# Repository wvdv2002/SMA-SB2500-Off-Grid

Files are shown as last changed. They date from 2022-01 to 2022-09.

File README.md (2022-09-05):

# SMA-SB2500-Off-Grid
The grid tie solar inverter SMA Sunny Boy SB2500 is a beautifully designed transformer isolated grid tie inverter. It is probably possible to convert it to an off grid batter inverter by reprogramming or redesigning the logic  board

Checkout my [hackaday.io](https://hackaday.io/project/183357-grid-tie-inverter-sma-sunny-boy-sb2500-openlogic) page for pictures of the inside of the inverter and a project log.

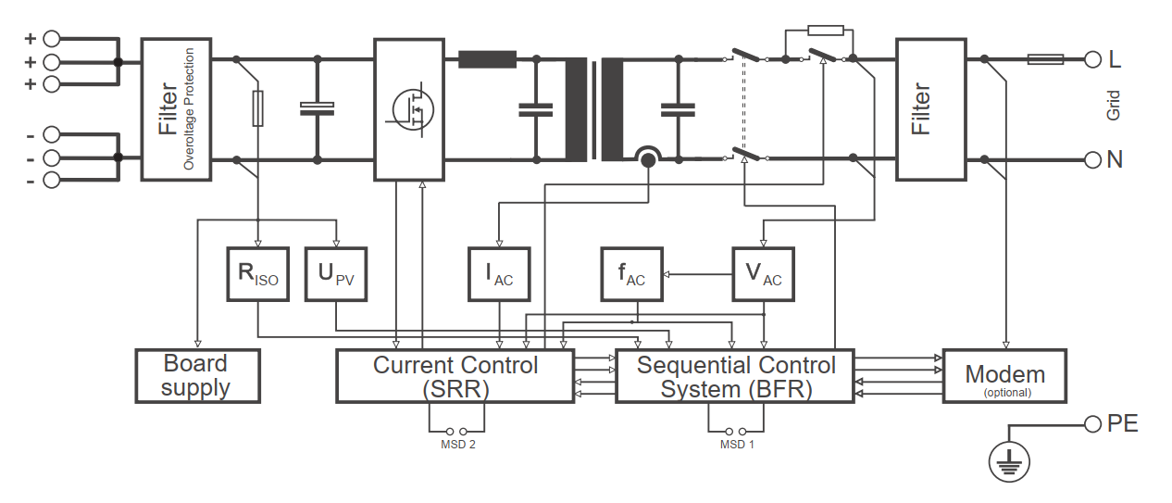
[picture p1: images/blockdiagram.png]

The block diagram from the SB2500 manual.

The inverter has an H-bridge with 4 IGBTs (SKW30NF60) driven by IR2113S mosfet drivers. These drive an 2mH inductor + 4.7uF capacitor step down converter and then a isolation transformer 153V primary/230V secondary 9.6A. On the grid side are three safety relais, EMC filtering and a measurement transformer for the logic board the measure the grid voltages.
All the logic is powered from the DC side, several voltages are generated using a switching power converter which generates all the drive voltages for the IGBT drivers and the logi board.
The logic board contains an SAFC808 microcontroller, probably with an interchangable AT70C020, 2 MBit memory chip, for grid monitoring and sequencing. A DSP56F803 from Freescale provides the switching waveforms. 

The layout is drawn in Kicad. 

Exported kicad images (probably not up to date) are in the images folder. 

The src folder can contain the Freescale DSP code.

The datasheets folder contains datasheets of most of the electronic parts in the inverter.

# Already known
* Switching frequency 16khz
* 250 - 600VDC max input voltage range
* 2200W nominal power
* It is probably challenging to reuse the logic board, as one of the microcontrollers is OTP, maybe it can be bridged and only the DSP used. But then you need a [Freescale USB TAP](https://www.nxp.com/docs/en/user-guide/CWH-UTP-UG.pdf) JTAG programmer to program the DSP. The development environment is not easy to download, but it looks easy to use. 
* The [DEFCON 18 badge](https://media.defcon.org/DEF%20CON%2018/DEF%20CON%2018%20badge/) has used the same development environment and might be a good place to download the development environment and some general guide.

# Already done
* Basic pinout of the logic board connection in Kicad
* Basic layout of the power board important parts in Kicad
* Design new logic board 
* Check if pinout is correct by measuring the voltages on the logic board connector 
* Check all voltage ranges of the voltage measurements on the logic board connector
* Written basic control software
* Light a lightbulb using AC voltage of 100vac at the output of the inverter.

# TODO
* Try to reprogram logic board

# Interesting links
* [Arduino based grid tie inverter repo](https://github.com/MartinStokroos/openMicroInverter)
* [Pic based grid tie inverter repo](https://github.com/rajeshfarswan/UDQ-GRID-1P)
* [STM based grid tie inverter repo](https://github.com/fotherja/Grid_Tie_Inverter)
* [STM based grid tie inverter 2 repo](https://github.com/fotherja/Grid_Tie_Inverter_2)
* [TIVA-C based grid tie inverter](https://github.com/srpoyrek/NIVAS)

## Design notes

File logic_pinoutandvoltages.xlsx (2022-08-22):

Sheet: 25
1 | VSUP1 | 13V |  | Voltages Measured from logic board ground plane
2 | GND | 0V
3 | VSUP2 | -13V
4 | VSUP3 | 3v3
5 | GND | 0V
6 | 5V | 5.09V
7 | GND | 0v
8 | GND | 0v (ground of the 5.09v
9 | AC Modem | 0v
10 | GND | 0v
11 | GND | 0v
12 | GND | 1.409
13 | B1_HIN | 0
14 | B0_LIN | 0
15 | B1_HIN | 0
16 | B1_LIN | 0
17 | GND | 0
18 | 5v | 5.09v
19 | BS_SHUT | 0.034
20 | GND | 0 |  |  | Weird 0 ohm resistor to GND setup, might be indicator if 2500watt or 3000watt or 2000 watt
21 | REL0 | 0
22 | REL0_CHK | 0 | Relay0, 4.08-4.5v if relay is open, otherwise 0, but only if 230v is switched on
23 | REL1_CHK | 0 | Relay1, 4.08-4.5v if relay is open, otherwise 0, but only if 230v is switched on
24 | REL1 | 0
25 | GND | 0
26 | GND | 0
27 | CURSENS | 0 | 15A is 2.5v, -15A is -2.5v. Measurement range is -60A tot 60A, so -10 tot 10v, for 2500watt, you need 2500/230*sqrt(2) = +/- 15A, seems to be buffered by LM258
28 | TRAFO | 0 | @ 230VAC you get -4.88 to 4.88v on this pin. There do not seem to be phase differences
29 | TEMPHEAT | 1.41v | @16 degrees C
30 | VDCBUS | 1.3436 | bij 177.68v, max bus is 650v, so 650/177.68*1.3436 = 4.91v, is 4.91/32*22= |  |  | Buffered by LM258, so just divide down from 5v to 3.3v
31 | VARISTOR | 1.9885 | drops if varistor removed on edge |  |  | Pullup to 5v with 4.7k, 2x pull down to gnd via opamp and diode.
32 | ???, ADC | 1.6198 | ???? |  |  | 100ohm resistor to testpoint, divider with 4.7k to gnd
33 | GND | 0
34 | GND | 0
35 |  | 0 |  | Weird 0 ohm resistor to GND setup, might be indicator if 2500watt or 3000watt or 2000 watt
36 | ?? | 4.5691 |  | Pullup to 5v via 500ohm resistor, to giant square testpoint
37 |  | 0 |  | Weird 0 ohm resistor to GND setup, might be indicator if 2500watt or 3000watt or 2000 watt
38 |  | 0 |  | Weird 0 ohm resistor to GND setup, might be indicator if 2500watt or 3000watt or 2000 watt
39 |  | 0 |  | Weird 0 ohm resistor to GND setup, might be indicator if 2500watt or 3000watt or 2000 watt
40 |  | 0 |  | 1k resistor divider to point, point 10k resistor divider to GND
How to control:
Measure VDCBus, feedforward to PWM signal at 16khz to make 230v (153v before transformer), Use TRAFO input as feedback to correct via PID loop?
Maybe use current measurement and resistance of transformer to feedforward to PWM signal too.

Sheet: LCD pins
n
There are 14 pins to connect to the main board |  |  | 27m21 precision amplifier on LCD board.
 |  |  | 2x7 2.54mm female on LCD board
LCD pin
1 | GND | 14 pin mainboard connector
2 | 5V | 1 | 5V and via 2ohm resistor to 5V LED
3 | Vo | 2 | GND
4 | RS | 3 | EN LCD
5 | R/W | 4 | R/W LCD
6 | EN | 5 | RS LCD
7 | D0 | 6 | LCD Backlight on/off
8 | D1 | 7 | GND
9 | D2 | 8 | microphone amplifier out
10 | D3 | 9 | Switch A, pull to GND
11 | D4 | 10 | Switch B, pull to GND
12 | D5 | 11 | D4
13 | D6 | 12 | D5
14 | D7 | 13 | D6
15 | 5V LED | 14 | D7
16 | GND LED

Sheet: COMM pins
Communication board has 2 connectors
On inverter side:
MAX253 | 1W primary side isolated power supply driver,
HCT14 | Hex inverting schmitt trigger
sfh6156-3 | optocoupler, 4X
comm side:
MAX487E | RS485 chip
KF50 | 5v low drop 0.4v, inhibit is not used and connected to GND
SM712 | 12V TVS diode
 |  |  |  | OPTO
COMM |  | INV |  | 1 | RX RS485/RS232 |  | 6A
1 | COMM PIN 1 | 1 | NC | 2 | TX RS485 |  | 4Y
2 | RS232 RX, OPTO 1 | 2 | NC | 3 | TX ENA |  | 1Y
3 | RS 485 A | 3 | RX opto, 5Y | 4 | RX ENA |  | 2Y
4 | 120ohm to A | 4 | TX ENA, opto 3
5 | RS 485 A | 5 | TX 485, opto 2 |  | 5A - 6Y | connected
6 | RS 485 B | 6 | NC
7 | 50 ohm to GND | 7 | RX ENA, opto 4, high = uit
8 | RS 485 B | 8 | NC
9 | GND | 9 | GND
10 | COMM PIN 1 | 10 | 5v
 |  | 11 | NC
 |  | 12 | 10V
 |  | 13 | receive pin, 3Y
 |  | 14 | NC

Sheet: logicboard
ADR02A | +2.5v voltage reference
hct74 | dual D type flipflop
lp211 | Low power strobed comparator
hct259D | 8 bit Addressable latch
bs62lv256sip5 | 32KByte Sram
at27c020 | 2MBIT OTP EPROM
lm258 | dual opamp
MC33275D−3.3G | 3.3v regulator low drop 300ma
OP177G | ultra precision opamp, 25uV offset
HB02 | 74ahct02 quad NOR Gates
DSP56F803 | 16 bit DSP/microcontroller
safc505 | 8 bit microcontroller
AT25080 | 1Kbyte EEPROM SPI
HCT08 | Quad AND gates
HCT157 | Quad 2 input multiplexer
C07 | 12bit 555 ksps AD742BRT, SPI
C14 | 8 pin package???
HB14 | 74HCT14, hex schmitt trigger inverters
HB32 | Quad 2 input OR gates
HB138 | 74HAHCT138 3 to 8 line decoders
HB574 | Octal D type latches with 3 state outputs and clock
HB573 | Octal D type latches with 3 state outputs and latch enable
HB245 | Octal bus transceivers with 3-state outputs

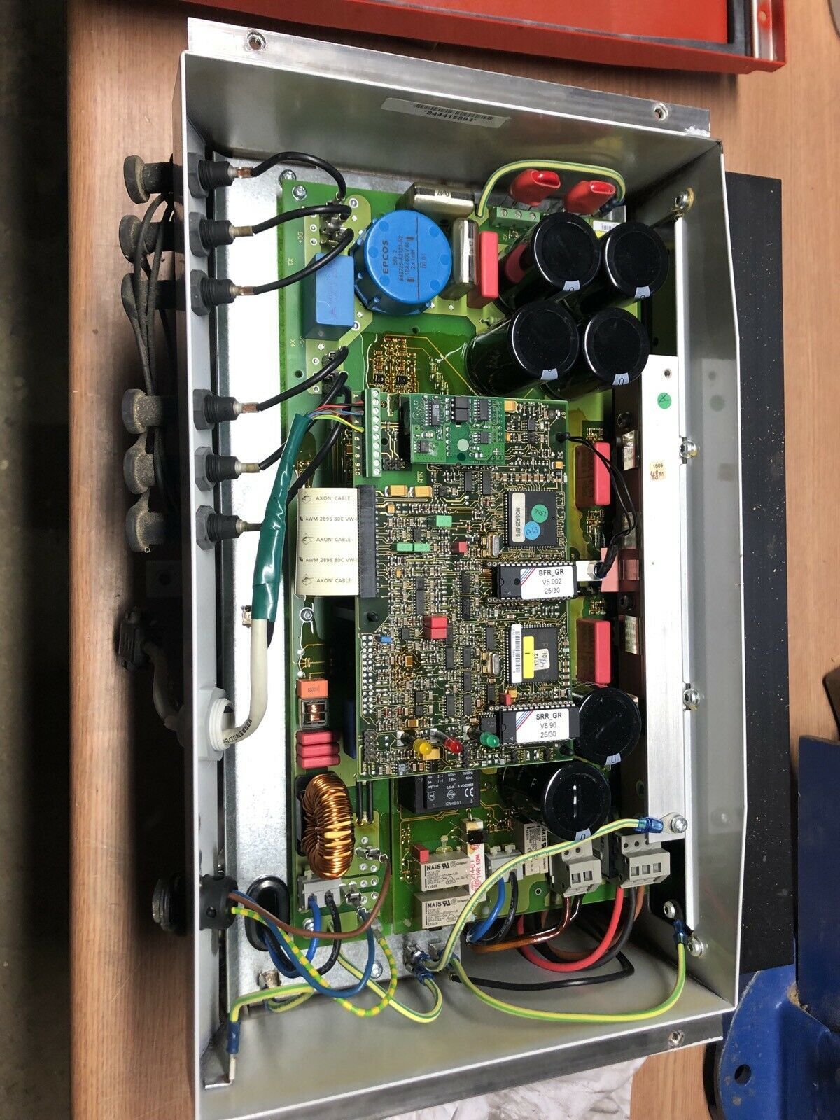
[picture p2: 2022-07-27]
images/olderdesign.jpg

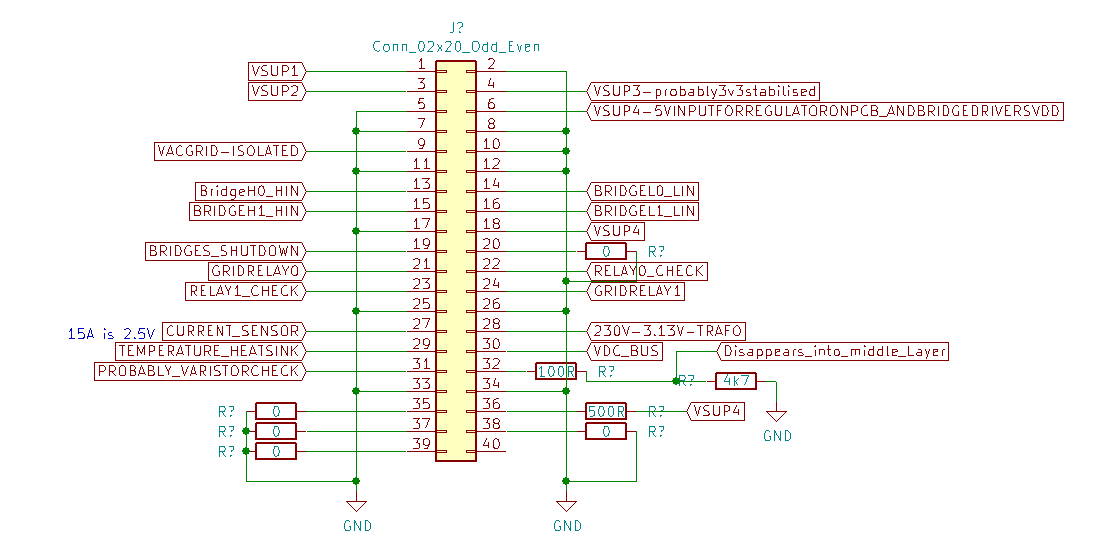
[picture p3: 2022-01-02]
images/logicpinout.png

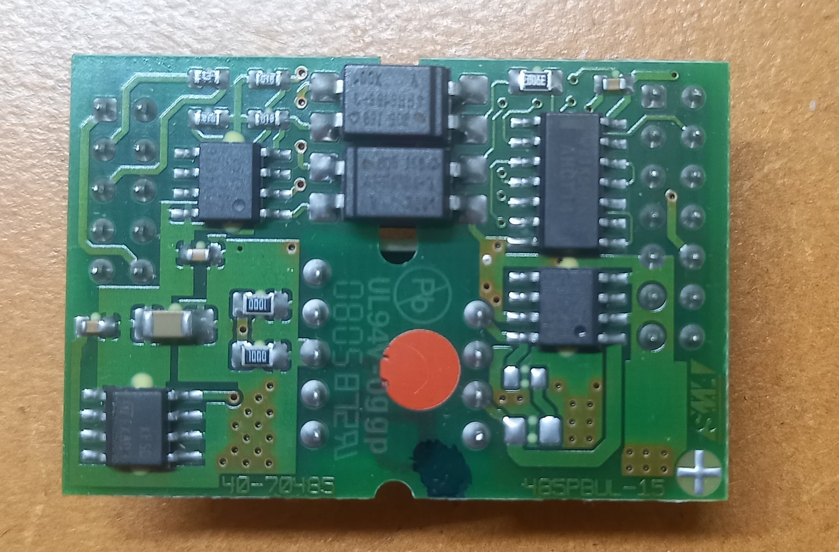
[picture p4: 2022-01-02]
images/commboard.jpg

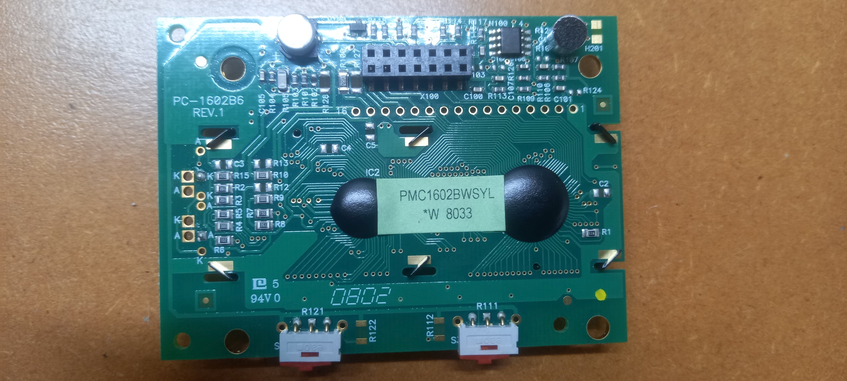
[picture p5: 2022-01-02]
images/lcdunderside.jpg

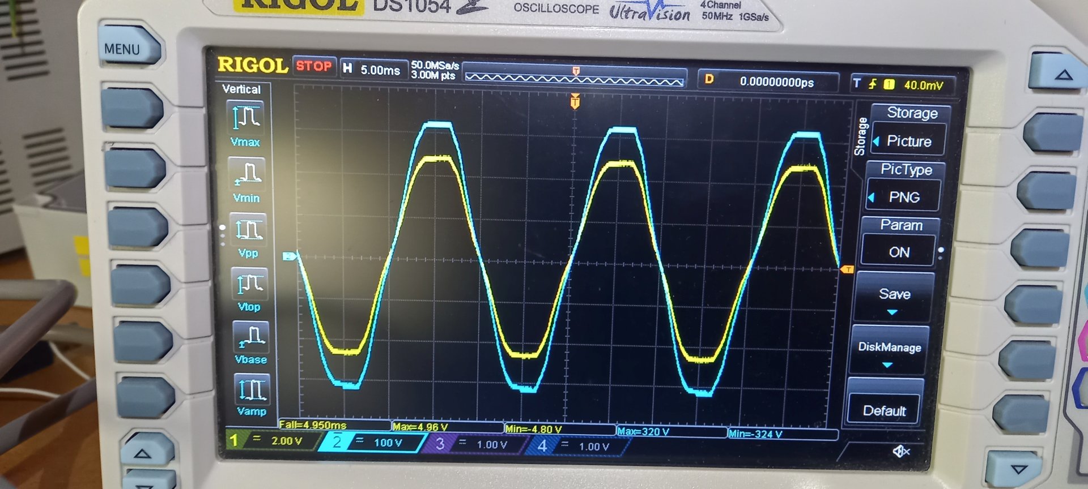
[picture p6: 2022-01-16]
images/waveform230v.jpg

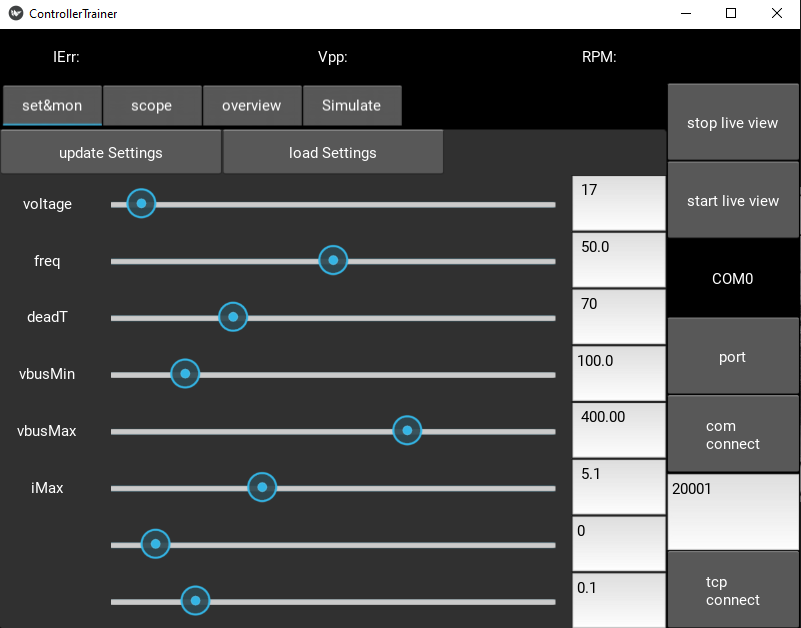
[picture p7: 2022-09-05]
images/newController/ControllerTrainer.png

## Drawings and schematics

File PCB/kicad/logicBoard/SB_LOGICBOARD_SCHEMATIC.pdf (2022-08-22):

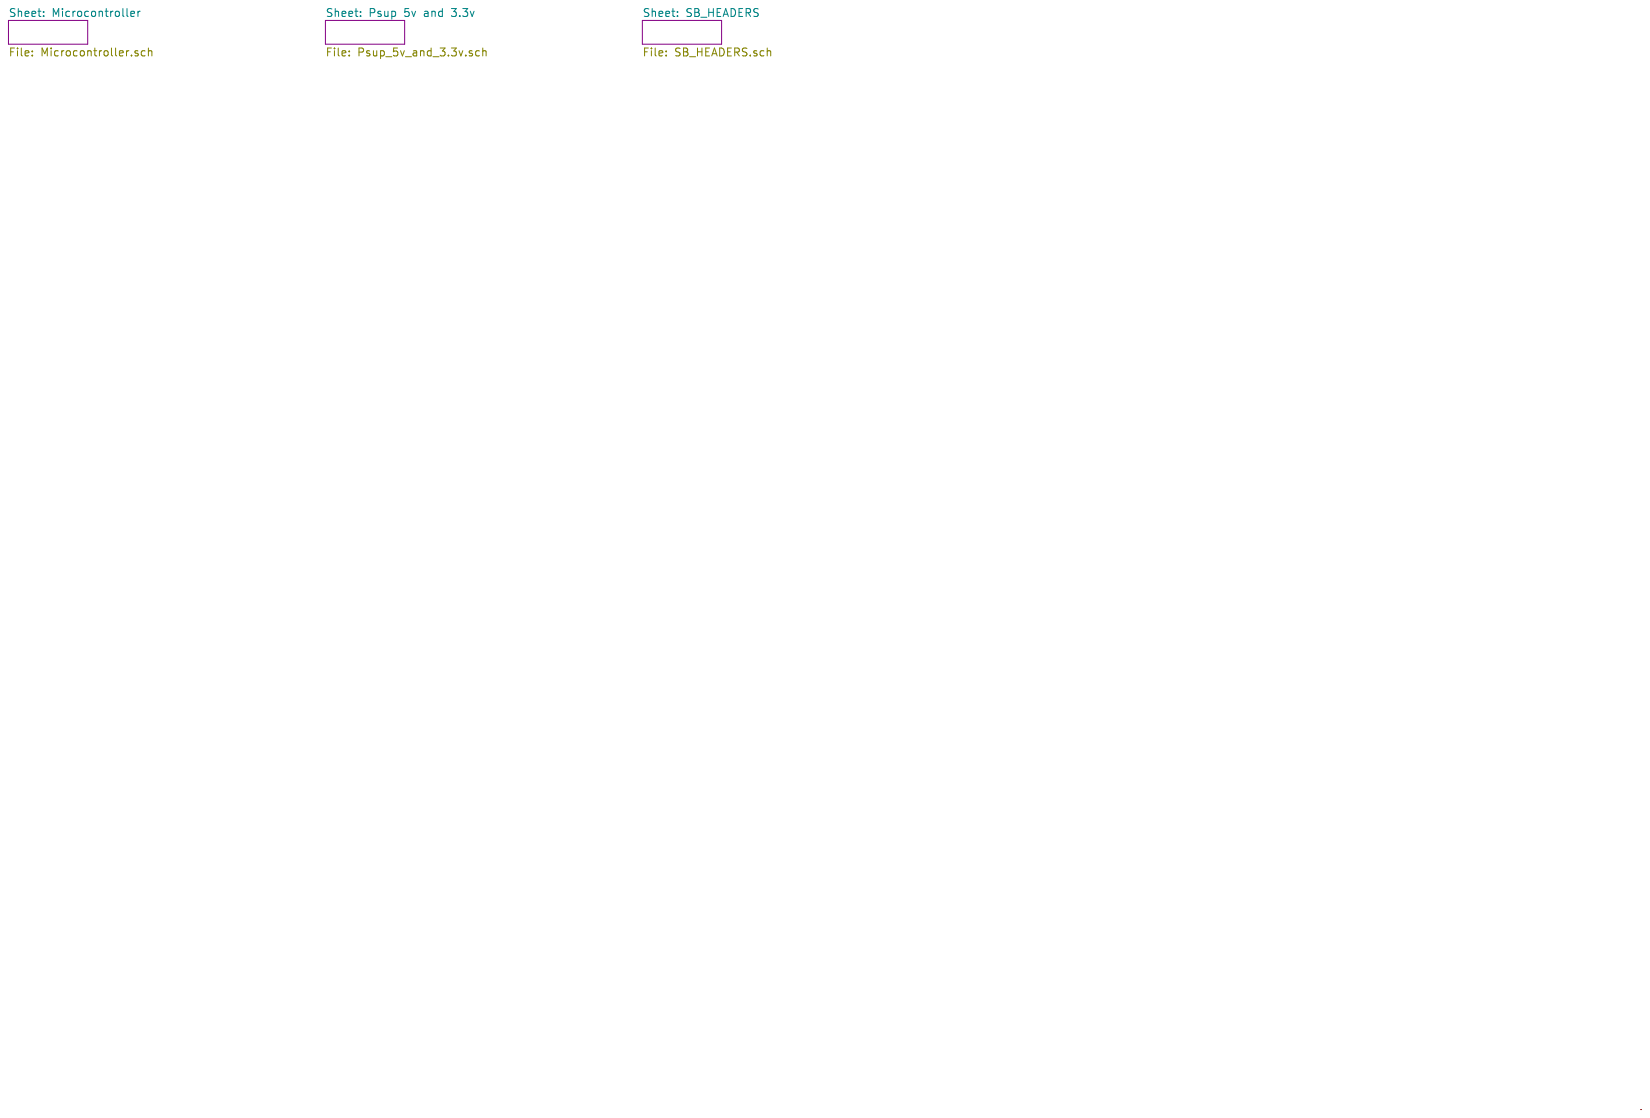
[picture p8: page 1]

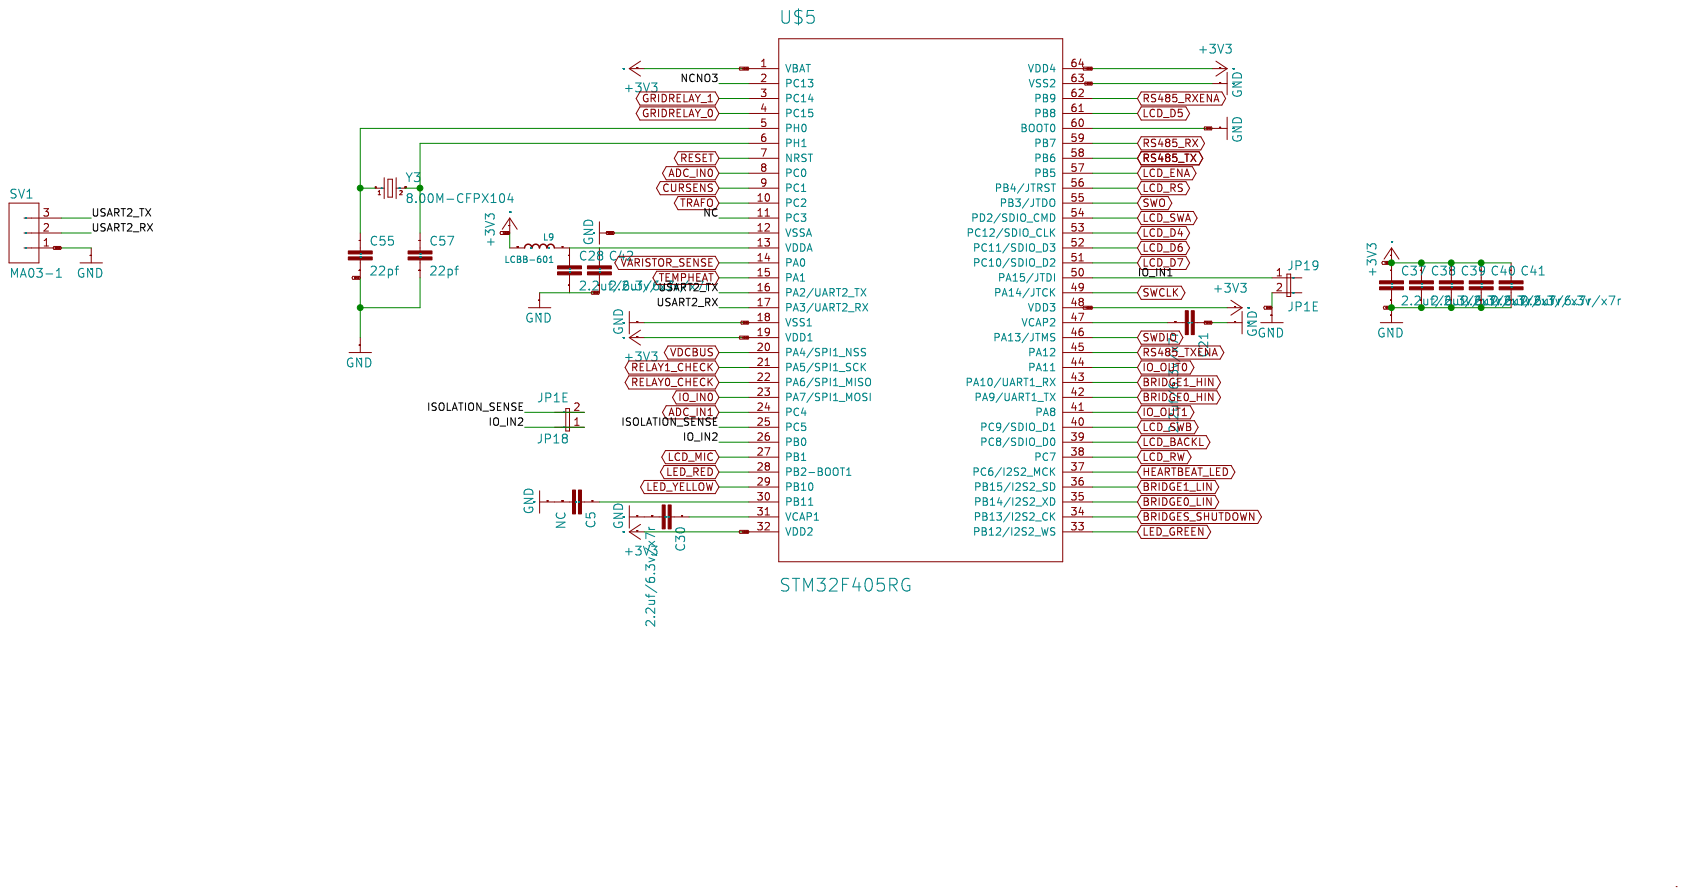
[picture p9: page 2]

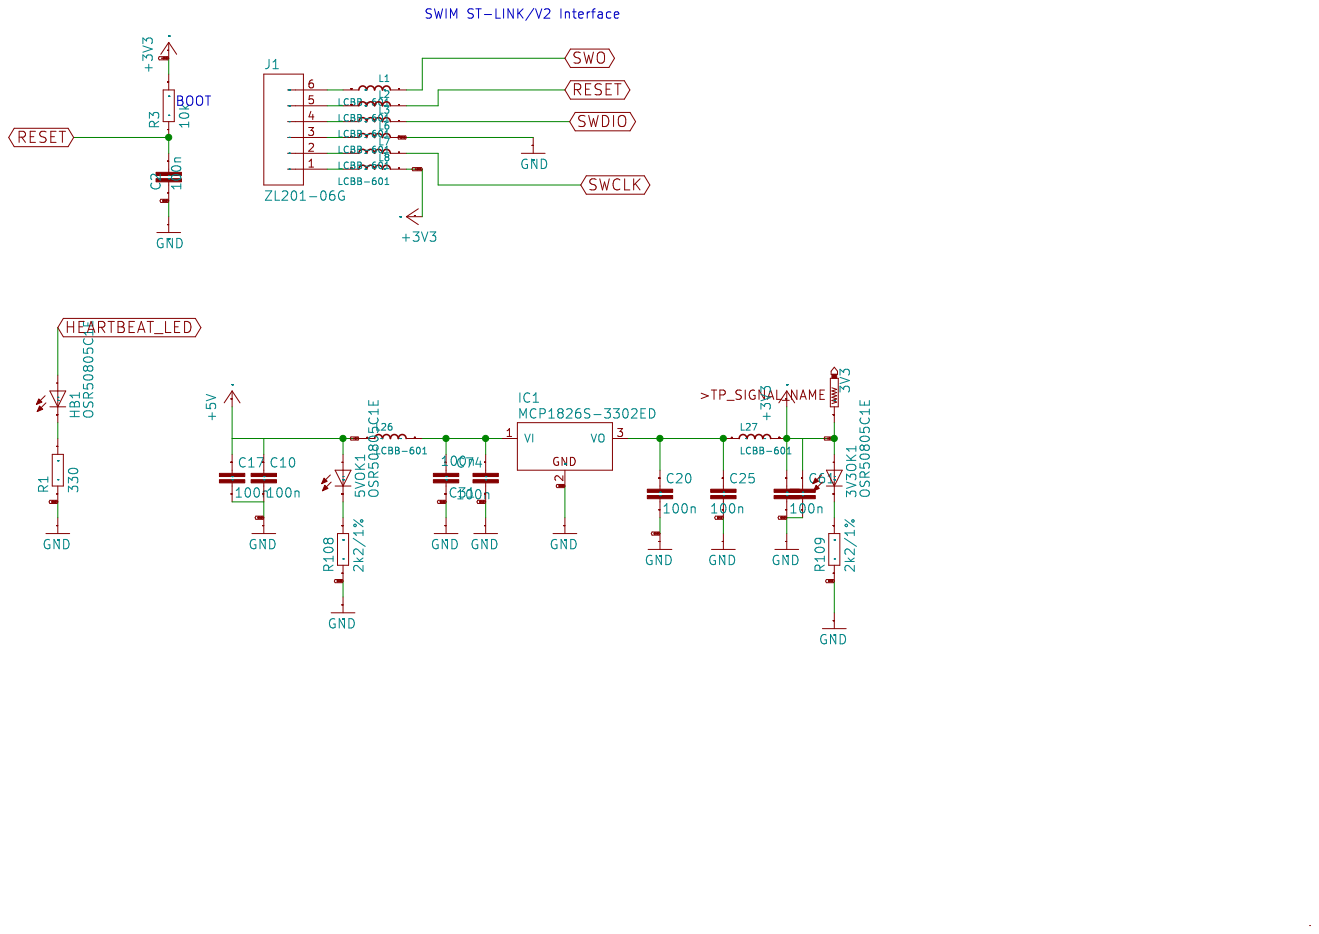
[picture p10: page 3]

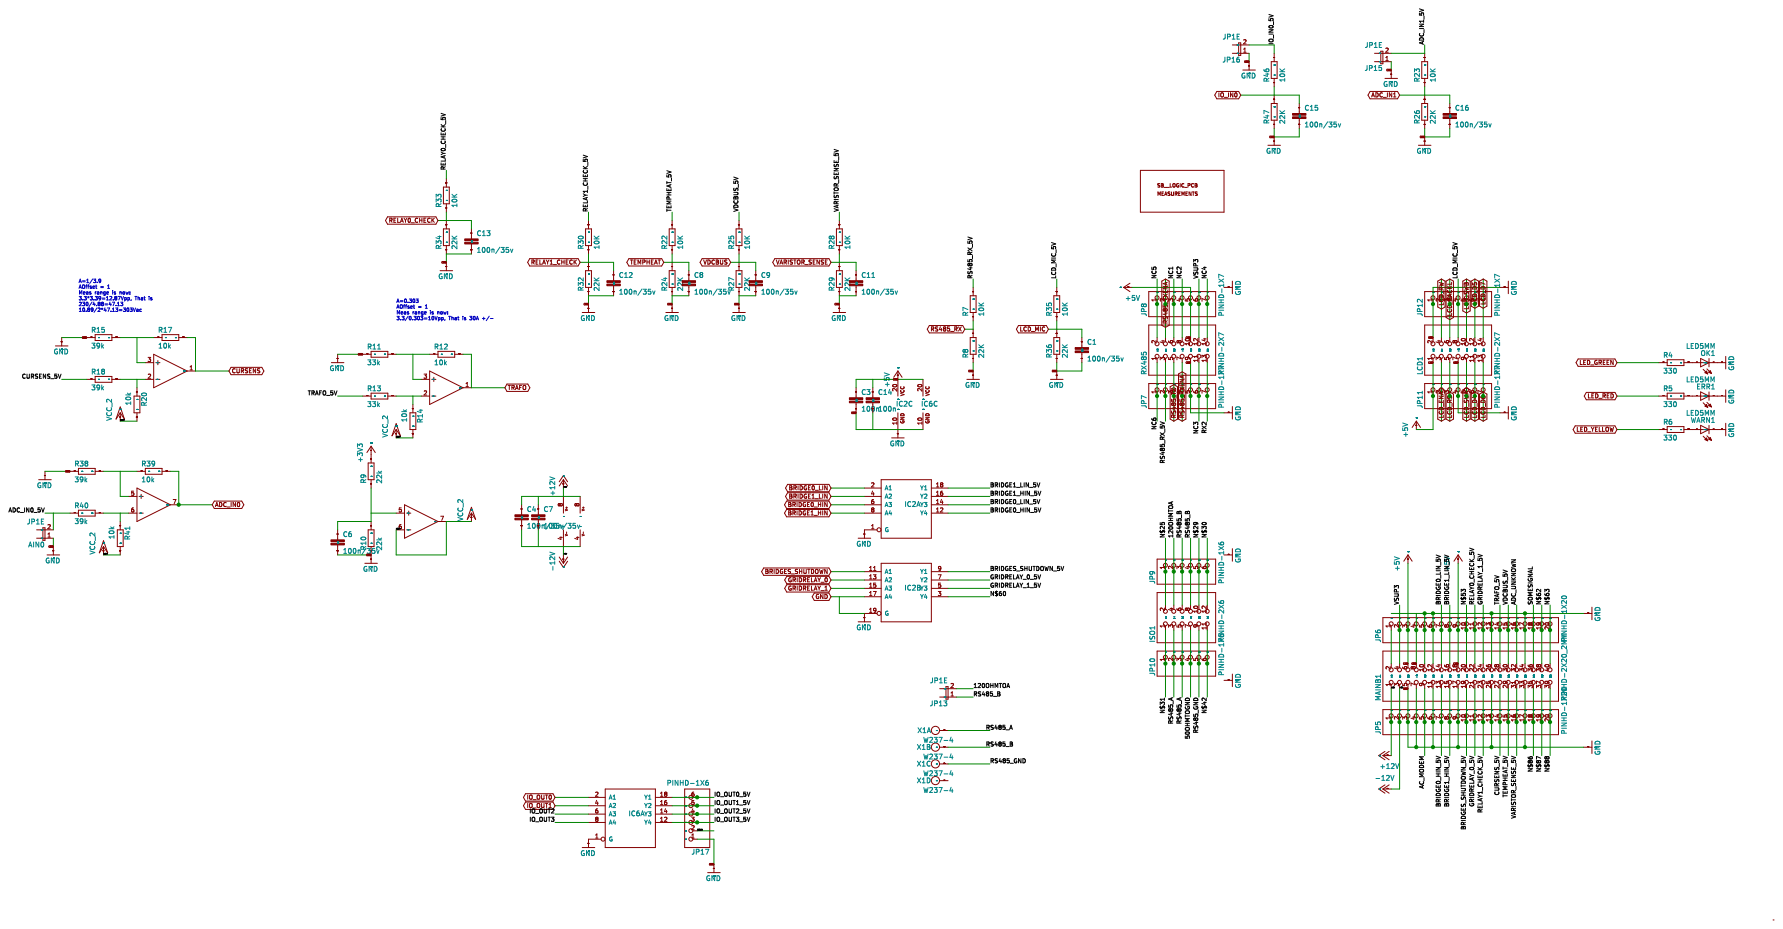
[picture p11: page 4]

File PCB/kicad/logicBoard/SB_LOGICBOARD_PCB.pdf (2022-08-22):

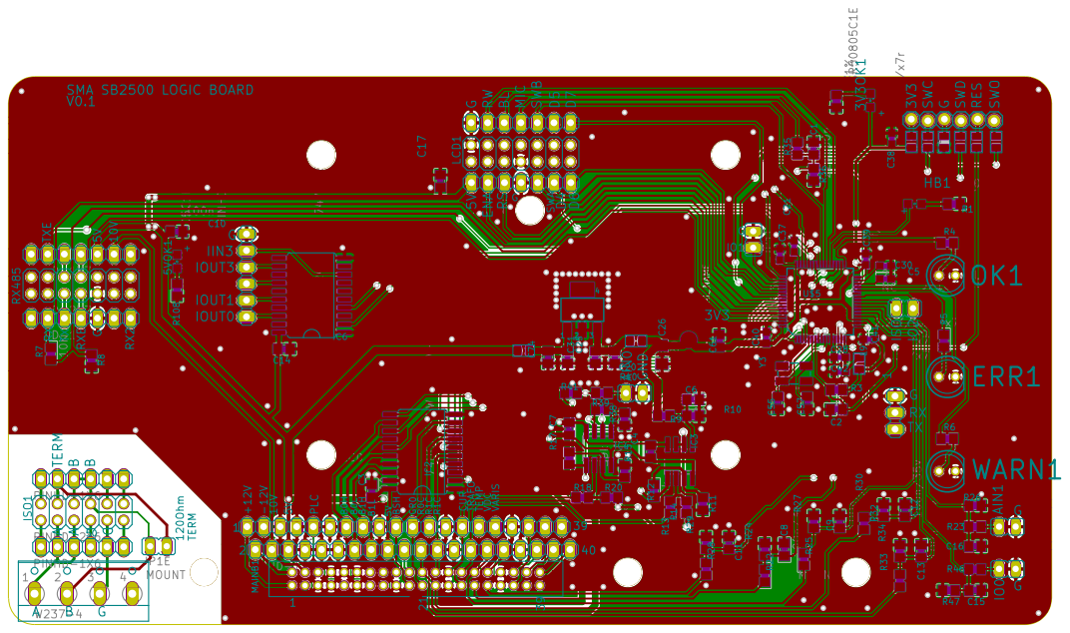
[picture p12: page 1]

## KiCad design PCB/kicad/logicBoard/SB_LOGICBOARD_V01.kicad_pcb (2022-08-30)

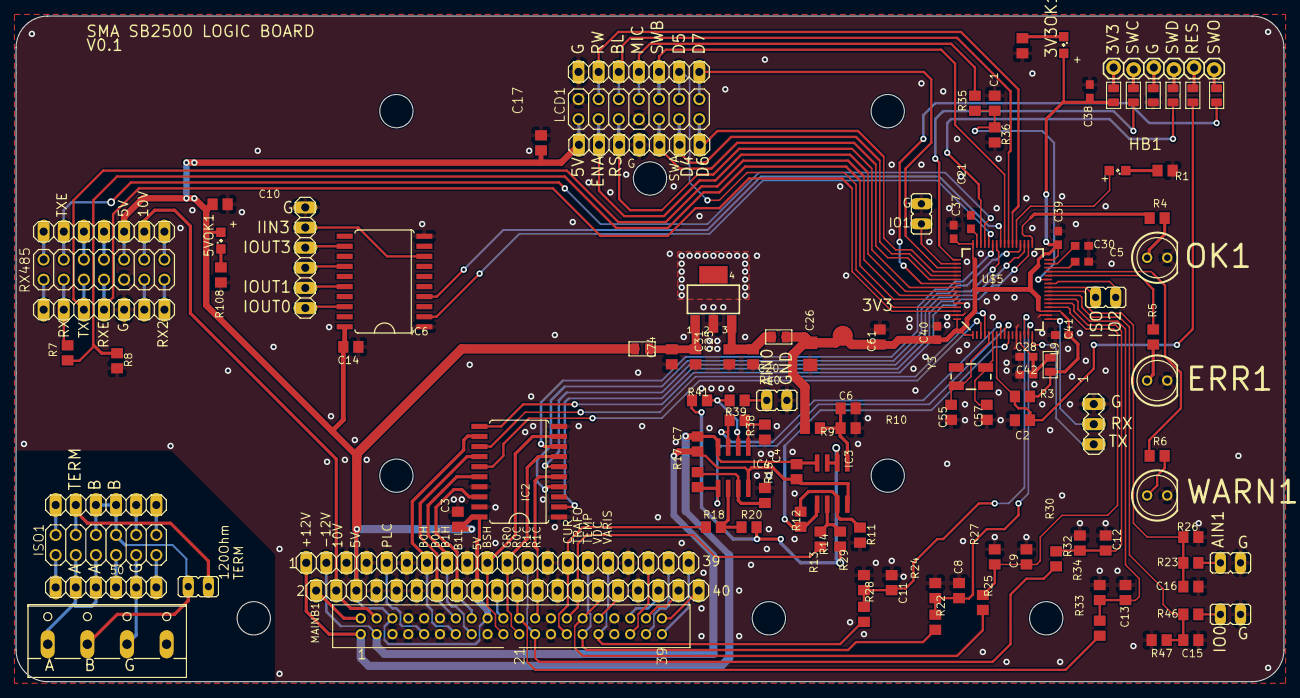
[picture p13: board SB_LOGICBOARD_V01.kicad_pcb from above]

Board: 2 copper layers, 160.0 x 84.0 mm, 119 parts (0 on the bottom side), 132 nets.

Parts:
3V3: NC; B2,54
3V3OK1, 5VOK1: OSR50805C1E; SML0805
AIN0: JP1E; JP1
C1, C4, C6, C7, C8, C9, C11, C12, C13, C15, C16: 100n/35v; C0805
C2, C3, C10, C14, C17, C20, C25, C31, C61, C74: 100n; C0805
C5: NC; C0603
C21, C28, C30, C37, C38, C39, C40, C41, C42: 2.2uf/6.3v/x7r; C0603
C26: 1206DD106KAT2A; C1206
C55, C57: 22pf; C0805
ERR1: LED5MM
HB1: OSR50805C1E; SML0805
IC1: MCP1826S-3302ED; SOT223
IC2, IC6: 74HCT244DW OR 74VHCT541A; SO20W
IC3, IC4: LM358D; SO08
ISO1: PINHD-2X6; 2X06
J1: ZL201-06G; 1X06_LOCK
JP5, JP6: PINHD-1X20; 1X20
JP7, JP8, JP11, JP12: PINHD-1X7; 1X07
JP9, JP10, JP17: PINHD-1X6; 1X06
JP13, JP15, JP16, JP18, JP19: JP1E; JP1
L1, L2, L3, L6, L7, L8, L9, L26, L27: LCBB-601; L0805
LCD1: PINHD-2X7; 2X07
MAINB1: PINHD-2X20_2MM; 2X20_2MM
OK1: LED5MM
R1, R4, R5, R6: 330; R0805
R3, R12, R14, R17, R20, R39, R41: 10k; R0805
R7, R22, R23, R25, R28, R30, R33, R35, R46: 10K; R0805
R8, R24, R26, R27, R29, R32, R34, R36, R47: 22K; R0805
R9, R10: 22k; R0805
R11, R13: 33k; R0805
R15, R18, R38, R40: 39k; R0805
R108, R109: 2k2/1%; R0805
RX485: PINHD-2X7; 2X07
SV1: MA03-1
U$1: SB_LOGIC_PCB; SB-PCB
U$5: STM32F405RG; TQFP64
WARN1: LED5MM
X1: W237-4
Y3: 8.00M-CFPX104; CRYSTAL-SMD-5X3

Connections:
+3V3: 3V3.TP, 3V3OK1.A, C26.2, C37.1, C38.1, C39.1, C40.1, C41.1, C61.2, L8.1, L9.2, L27.2, R3.2, R9.2, U$5.1, U$5.19, U$5.32, U$5.48, U$5.64
+5V: 5VOK1.A, C3.1, C10.2, C14.1, C17.2, IC2.20, IC6.20, JP6.3, JP6.9, JP8.5, JP11.1, L26.1, LCD1.1, MAINB1.6, MAINB1.18, RX485.10
+12V: C4.1, C7.1, IC3.8, IC4.8, JP5.1, MAINB1.1
-12V: C4.2, C7.2, IC3.4, IC4.4, JP5.2, MAINB1.3
/Microcontroller/IO_IN1: JP19.1, U$5.50
/Microcontroller/IO_IN2: JP18.1, U$5.26
/Microcontroller/ISOLATION_SENSE: JP18.2, U$5.25
/Microcontroller/USART2_RX: SV1.2, U$5.17
/Microcontroller/USART2_TX: SV1.3, U$5.16
/SB_HEADERS/50OHMTOGND: ISO1.7, JP10.4
/SB_HEADERS/120OHMTOA: ISO1.4, JP9.2, JP13.2
/SB_HEADERS/AC_MODEM: JP5.5, MAINB1.9
/SB_HEADERS/ADC_IN0_5V: AIN0.2, R40.1
/SB_HEADERS/ADC_IN1_5V: JP15.2, R23.2
/SB_HEADERS/ADC_UNKNOWN: JP6.16, MAINB1.32
/SB_HEADERS/BRIDGE0_HIN_5V: IC2.12, JP5.7, MAINB1.13
/SB_HEADERS/BRIDGE0_LIN_5V: IC2.14, JP6.7, MAINB1.14
/SB_HEADERS/BRIDGE1_HIN_5V: IC2.16, JP5.8, MAINB1.15
/SB_HEADERS/BRIDGE1_LIN_5V: IC2.18, JP6.8, MAINB1.16
/SB_HEADERS/BRIDGES_SHUTDOWN_5V: IC2.9, JP5.10, MAINB1.19
/SB_HEADERS/CURSENS_5V: JP5.14, MAINB1.27, R18.1
/SB_HEADERS/GRIDRELAY_0_5V: IC2.7, JP5.11, MAINB1.21
/SB_HEADERS/GRIDRELAY_1_5V: IC2.5, JP6.12, MAINB1.24
/SB_HEADERS/IO_IN0_5V: JP16.2, R46.2
/SB_HEADERS/IO_OUT0_5V: IC6.18, JP17.6
/SB_HEADERS/IO_OUT1_5V: IC6.16, JP17.5
/SB_HEADERS/IO_OUT2_5V: IC6.14, JP17.4
/SB_HEADERS/IO_OUT3: IC6.8, JP17.2
/SB_HEADERS/IO_OUT3_5V: IC6.12, JP17.3
/SB_HEADERS/LCD_MIC_5V: JP12.4, LCD1.8, R35.2
/SB_HEADERS/N$25: ISO1.2, JP9.1
/SB_HEADERS/N$29: ISO1.10, JP9.5
/SB_HEADERS/N$30: ISO1.12, JP9.6
/SB_HEADERS/N$31: ISO1.1, JP10.1
/SB_HEADERS/N$42: ISO1.11, JP10.6
/SB_HEADERS/N$53: JP6.10, MAINB1.20
/SB_HEADERS/N$62: JP6.19, MAINB1.38
/SB_HEADERS/N$63: JP6.20, MAINB1.40
/SB_HEADERS/N$86: JP5.18, MAINB1.35
/SB_HEADERS/N$87: JP5.19, MAINB1.37
/SB_HEADERS/N$88: JP5.20, MAINB1.39
/SB_HEADERS/NC1: JP8.3, RX485.6
/SB_HEADERS/NC2: JP8.4, RX485.8
/SB_HEADERS/NC3: JP7.6, RX485.11
/SB_HEADERS/NC4: JP8.7, RX485.14
/SB_HEADERS/NC5: JP8.1, RX485.2
/SB_HEADERS/NC6: JP7.1, RX485.1
/SB_HEADERS/RELAY0_CHECK_5V: JP6.11, MAINB1.22, R33.2
/SB_HEADERS/RELAY1_CHECK_5V: JP5.12, MAINB1.23, R30.2
/SB_HEADERS/RS485_A: ISO1.3, ISO1.5, JP10.2, JP10.3, X1.1
/SB_HEADERS/RS485_B: ISO1.6, ISO1.8, JP9.3, JP9.4, JP13.1, X1.2
/SB_HEADERS/RS485_GND: ISO1.9, JP10.5, X1.3
/SB_HEADERS/RS485_RX_5V: JP7.2, R7.2, RX485.3
/SB_HEADERS/RX2: JP7.7, RX485.13
/SB_HEADERS/SOMESIGNAL: JP6.18, MAINB1.36
/SB_HEADERS/TEMPHEAT_5V: JP5.15, MAINB1.29, R22.2
/SB_HEADERS/TRAFO_5V: JP6.14, MAINB1.28, R13.1
/SB_HEADERS/VARISTOR_SENSE_5V: JP5.16, MAINB1.31, R28.2
/SB_HEADERS/VDCBUS_5V: JP6.15, MAINB1.30, R25.2
/SB_HEADERS/VSUP3: JP6.2, JP8.6, MAINB1.4, RX485.12
ADC_IN0: IC4.7, R39.2, U$5.8
ADC_IN1: C16.1, R23.1, R26.2, U$5.24
BRIDGE0_HIN: IC2.6, U$5.42
BRIDGE0_LIN: IC2.2, U$5.35
BRIDGE1_HIN: IC2.8, U$5.43
BRIDGE1_LIN: IC2.4, U$5.36
BRIDGES_SHUTDOWN: IC2.11, U$5.34
CURSENS: IC4.1, R17.2, U$5.9
GND: AIN0.1, C1.2, C2.1, C3.2, C5.2, C6.2, C8.2, C9.2, C10.1, C11.2, C12.2, C13.2, C14.2, C15.2, C16.2, C17.1, C20.1, C21.1, C25.1, C26.1, C28.2, C30.2, C31.1, C37.2, C38.2, C39.2, C40.2, C41.2, C42.2, C55.2, C57.2, C61.1, C74.2, ERR1.K, IC1.2, IC2.1, IC2.10, IC2.17, IC2.19, IC6.1, IC6.10, JP5.3, JP5.4, JP5.6, JP5.9, JP5.13, JP5.17, JP6.4, JP6.5, JP6.6, JP6.13, JP6.17, JP7.5, JP11.4, JP12.1, JP15.1, JP16.1, JP17.1, JP19.2, L6.1, LCD1.2, LCD1.7, MAINB1.5, MAINB1.7, MAINB1.8, MAINB1.10, MAINB1.11, MAINB1.12, MAINB1.17, MAINB1.25, MAINB1.26, MAINB1.33, MAINB1.34, OK1.K, R1.1, R8.1, R10.1, R11.1, R15.1, R24.1, R26.1, R27.1, R29.1, R32.1, R34.1, R36.1, R38.1, R47.1, R108.1, R109.1, RX485.9, SV1.1, U$5.12, U$5.18, U$5.60, U$5.63, WARN1.K
GRIDRELAY_0: IC2.13, U$5.4
GRIDRELAY_1: IC2.15, U$5.3
HEARTBEAT_LED: HB1.A, U$5.37
IO_IN0: C15.1, R46.1, R47.2, U$5.23
IO_OUT0: IC6.2, U$5.44
IO_OUT1: IC6.4, U$5.41
LCD_BACKL: JP12.3, LCD1.6, U$5.39
LCD_D4: JP11.6, LCD1.11, U$5.53
LCD_D5: JP12.6, LCD1.12, U$5.61
LCD_D6: JP11.7, LCD1.13, U$5.52
LCD_D7: JP12.7, LCD1.14, U$5.51
LCD_ENA: JP11.2, LCD1.3, U$5.57
LCD_MIC: C1.1, R35.1, R36.2, U$5.27
LCD_RS: JP11.3, LCD1.5, U$5.56
LCD_RW: JP12.2, LCD1.4, U$5.38
LCD_SWA: JP11.5, LCD1.9, U$5.54
LCD_SWB: JP12.5, LCD1.10, U$5.40
LED_GREEN: R4.1, U$5.33
LED_RED: R5.1, U$5.28
LED_YELLOW: R6.1, U$5.29
unnamed: 3V3OK1.C, R109.2
unnamed: 5VOK1.C, R108.2
unnamed: C5.1, U$5.30
unnamed: C6.1, IC3.5, R9.1, R10.2
unnamed: C20.2, C25.2, IC1.3, L27.1
unnamed: C21.2, U$5.47
unnamed: C28.1, C42.1, L9.1, U$5.13
unnamed: C30.1, U$5.31
unnamed: C31.2, C74.1, IC1.1, L26.2
unnamed: C55.1, U$5.5, Y3.1
unnamed: C57.1, U$5.6, Y3.3
unnamed: ERR1.A, R5.2
unnamed: HB1.C, R1.2
unnamed: IC3.2, R13.2, R14.1
unnamed: IC3.3, R11.2, R12.1
unnamed: IC4.2, R18.2, R20.1
unnamed: IC4.3, R15.2, R17.1
unnamed: IC4.5, R38.2, R39.1
unnamed: IC4.6, R40.2, R41.1
unnamed: J1.1, L8.2
unnamed: J1.2, L7.2
unnamed: J1.3, L6.2
unnamed: J1.4, L3.2
unnamed: J1.5, L2.2
unnamed: J1.6, L1.2
unnamed: JP6.1, MAINB1.2
unnamed: OK1.A, R4.2
unnamed: R6.2, WARN1.A
RELAY0_CHECK: C13.1, R33.1, R34.2, U$5.22
RELAY1_CHECK: C12.1, R30.1, R32.2, U$5.21
RESET: C2.2, L2.1, R3.1, U$5.7
RS485_RX: R7.1, R8.2, U$5.59
RS485_RXENA: JP7.4, RX485.7, U$5.62
RS485_TX: JP7.3, RX485.5, U$5.58
RS485_TXENA: JP8.2, RX485.4, U$5.45
SWCLK: L7.1, U$5.49
SWDIO: L3.1, U$5.46
SWO: L1.1, U$5.55
TEMPHEAT: C8.1, R22.1, R24.2, U$5.15
TRAFO: IC3.1, R12.2, U$5.10
VARISTOR_SENSE: C11.1, R28.1, R29.2, U$5.14
VCC/2: IC3.6, IC3.7, R14.2, R20.2, R41.2
VDCBUS: C9.1, R25.1, R27.2, U$5.20

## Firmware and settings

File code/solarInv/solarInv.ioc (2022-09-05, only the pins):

Mcu.UserName=STM32F405RGTx
PA0-WKUP.Signal=ADCx_IN0
PA1.GPIO_Label=TEMPHEAT
PA1.Signal=ADCx_IN1
PA10.GPIO_Label=BRIDGE1_HIN
PA10.Signal=S_TIM1_CH3
PA11.GPIO_Label=IO_OUT0
PA11.Signal=GPIO_Output
PA12.GPIO_Label=RS485_TXENA
PA12.Signal=GPIO_Output
PA13.Signal=SYS_JTMS-SWDIO
PA14.Signal=SYS_JTCK-SWCLK
PA15.GPIO_Label=IO_IN1
PA15.Signal=GPIO_Input
PA2.GPIO_Label=USART2_TX
PA2.Signal=USART2_TX
PA3.GPIO_Label=USART2_RX
PA3.Signal=USART2_RX
PA4.GPIO_Label=VDCBUS
PA4.Signal=ADCx_IN4
PA5.GPIO_Label=RELAY_CHECK1
PA5.Signal=ADCx_IN5
PA6.GPIO_Label=RELAY_CHECK0
PA6.Signal=ADCx_IN6
PA7.GPIO_Label=IO_IN0
PA7.Signal=ADCx_IN7
PA8.GPIO_Label=IO_OUT1
PA8.Signal=GPIO_Output
PA9.GPIO_Label=BRIDGE0_HIN
PA9.Signal=S_TIM1_CH2
PB0.GPIO_Label=IO_IN2
PB0.Signal=ADCx_IN8
PB1.GPIO_Label=LCD_MIC
PB1.Signal=ADCx_IN9
PB10.GPIO_Label=LED_YELLOW
PB10.Signal=GPIO_Output
PB11.GPIO_Label=DONOTUSECOMPATIBILITY
PB11.Signal=GPIO_Input
PB12.GPIO_Label=LED_GREEN
PB12.Signal=GPIO_Output
PB13.GPIO_Label=BRIDGES_SHUTDOWN
PB13.Signal=GPIO_Output
PB14.GPIO_Label=BRIDGE0_LIN
PB14.Signal=TIM1_CH2N
PB15.GPIO_Label=BRIDGE1_LIN
PB15.Signal=TIM1_CH3N
PB2.GPIO_Label=LED_RED
PB2.Signal=GPIO_Output
PB3.Signal=SYS_JTDO-SWO
PB4.GPIO_Label=LCD_RS
PB4.Signal=GPIO_Output
PB5.GPIO_Label=LCD_ENA
PB5.Signal=GPIO_Output
PB6.GPIO_Label=RS485_TX
PB6.Signal=USART1_TX
PB7.GPIO_Label=RS485_RX
PB7.Signal=USART1_RX
PB8.GPIO_Label=LCD_D5
PB8.Signal=GPIO_Output
PB9.GPIO_Label=RS485_RXENA
PB9.Signal=GPIO_Output
PC0.GPIO_Label=ADC_IN0
PC0.Signal=ADCx_IN10
PC1.GPIO_Label=CURSENS
PC1.Signal=ADCx_IN11
PC10.GPIO_Label=LCD_D7
PC10.Signal=GPIO_Output
PC11.GPIO_Label=LCD_D6
PC11.Signal=GPIO_Output
PC12.GPIO_Label=LCD_D4
PC12.Signal=GPIO_Output
PC14-OSC32_IN.GPIO_Label=GRIDRELAY_1
PC14-OSC32_IN.Signal=GPIO_Output
PC15-OSC32_OUT.GPIO_Label=GRIDRELAY_0
PC15-OSC32_OUT.Signal=GPIO_Output
PC2.GPIO_Label=TRAFO
PC2.Signal=ADCx_IN12
PC4.GPIO_Label=ADC_IN1
PC4.Signal=ADCx_IN14
PC5.GPIO_Label=ISOLATION_SENSE
PC5.Signal=ADCx_IN15
PC6.GPIO_Label=LED_HEARTBEAT
PC6.Signal=GPIO_Output
PC7.GPIO_Label=LCD_RW
PC7.Signal=GPIO_Output
PC8.GPIO_Label=LCD_BACKL
PC8.Signal=GPIO_Output
PC9.GPIO_Label=LCD_SWB
PC9.Signal=GPIO_Input
PD2.GPIO_Label=LCD_SWA
PD2.Signal=GPIO_Input

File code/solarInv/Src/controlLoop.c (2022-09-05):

/*
 * controlLoop.c
 *
 *  Created on: 11 aug. 2017
 *      Author: wvdv2
 */
#include "HardwareDefines.h"
#include "controlLoop.h"
#include "controlMonitor.h"
#include "filterCoeff.h"
#include "tm_stm32_filters.h"
#include "PID.h"
#include "temperature/Thermistor.h"
#include "libRelay.h"
#include "fanTask.h"
//#include "syncLoop.h"
#include "stm32f4xx_hal.h"
#include "arm_math.h"
adc3Results_t adc3Results[FILTERDEPTH];
adc2Results_t adc2Results[FILTERDEPTH];
adc1Results_t adc1Results[FILTERDEPTH];

solarFullControlState_t systemState;
solarSetPoints_t setPoint;
solarSetPoints_t setPointCopy;
solarAuxInputs_t auxInputs;
PID_t capacitorPid;

bool updateControl = false;
bool updateSetPoint = false;
uint32_t closeRelayTime=0;
float voutNow= 0.0;

void calculateTemperature(void);

#define DCRATIO (float) 0.999
TM_FILTER_FIR_F32_t* currentFIR;
TM_FILTER_FIR_F32_t* uCapFIR;
extern TIM_HandleTypeDef htim4;
extern TIM_HandleTypeDef htim2;

#define min(a, b) (((a) < (b)) ? (a) : (b))
#define max(a, b) (((a) > (b)) ? (a) : (b))

void controlLoop(void){
//	HAL_GPIO_WritePin(TEST_PIN_GPIO_Port, TEST_PIN_Pin, GPIO_PIN_SET);

	if(updateSetPoint){
		memcpy(&setPoint,&setPointCopy,sizeof(solarSetPoints_t));
//		pidSetTunings(&capacitorPid,setPoint.UCapP,setPoint.UCapI,setPoint.UCapD,P_ON_E);
//		auxInputs.Vpp = syncCalculateVpp();
		updateSetPoint = false;
		htim1.Instance->BDTR = (htim1.Instance->BDTR & 0xFFFFFF00) | setPoint.deadTime;
	}
	calculateInputs();
	calculateFilters();
	calculateState();

	switch(systemState.controlState.controlTaskState){
	case CONTROL_IDLE:
		if(HAL_GetTick()>10000){
			systemState.controlState.controlTaskState = CONTROL_WAITFOR_SAFESTART;
		}
		setDutyCycle(0.0);
		break;
	case CONTROL_WAITFOR_SAFESTART:
		HAL_GPIO_WritePin(BRIDGES_SHUTDOWN_GPIO_Port, BRIDGES_SHUTDOWN_Pin, 0);
		voutNow = 0.0;
		systemState.controlState.controlTaskState = CONTROL_RUNNING;
		__HAL_TIM_SetCounter(&htim2,0);
		HAL_TIM_Base_Start(&htim2);
		break;

	case CONTROL_RUNNING:
		setDutyCycle(getDutyCycle());
		break;

	case CONTROL_FIXED_DUTY_CYLE:
//		setDutyCycle(getDutyCycle());
		break;

	case CONTROL_STOPANDRESET:
		setDutyCycle(0.0);
		break;

	case CONTROL_SAFETY:
	case CONTROL_OVERVOLTAGE:
	case CONTROL_STOPPING:
	case CONTROL_OVERTEMPERATURE:
//		if(systemState.controlState.UCap<(float)7.0){
//			closeRelayTime = HAL_GetTick();
//			closeBridgeRelay();
//			systemState.controlState.controlTaskState++;
//		}
		break;
	case CONTROL_SAFETY_RELAYOFF:
		if(HAL_GetTick()-closeRelayTime>60*1000){ //restart after a minute automatically.
			systemState.controlState.controlTaskState = CONTROL_IDLE;
		}
		break;
	case CONTROL_OVERVOLTAGE_RELAYOFF:
	case CONTROL_OVERTEMPERATURE_RELAYOFF:
	case CONTROL_STOPPING_RELAYOFF:
	case CONTROL_POWERLOSS_RELAYOFF:
	case CONTROL_BRIDGEMALFUNCTION_RELAYOFF:
		if(HAL_GetTick()-closeRelayTime>200){
			setDutyCycle(0.0);
		}
		break;
	case CONTROL_STOPANDRESET_RELAYOFF:
		if((HAL_GetTick()-closeRelayTime)>5000){
			NVIC_SystemReset();
		}
		break;
	default:
		systemState.controlState.controlTaskState = CONTROL_IDLE;
	}

	if (systemState.inputs.VDCBUS < setPoint.vbusMin){
		setDutyCycle(0.0);
		HAL_GPIO_WritePin(BRIDGES_SHUTDOWN_GPIO_Port, BRIDGES_SHUTDOWN_Pin, 1);
		systemState.controlState.controlTaskState = CONTROL_SAFETY;
	}

	if (systemState.inputs.VDCBUS > setPoint.vbusMax){
		setDutyCycle(0.0);
		HAL_GPIO_WritePin(BRIDGES_SHUTDOWN_GPIO_Port, BRIDGES_SHUTDOWN_Pin, 1);
		systemState.controlState.controlTaskState = CONTROL_SAFETY;
	}

	//	HAL_GPIO_WritePin(TEST_PIN_GPIO_Port, TEST_PIN_Pin, GPIO_PIN_RESET);
}



void checkVACSupplyState(void){
	if(__HAL_TIM_GET_FLAG(&htim4,TIM_FLAG_UPDATE)){
		__HAL_TIM_CLEAR_FLAG(&htim4,TIM_FLAG_UPDATE);
		__HAL_TIM_SET_COUNTER(&htim4,0);
		if(systemState.controlState.controlTaskState != CONTROL_POWERLOSS_RELAYOFF){
//			HAL_GPIO_WritePin(TEST_PIN_GPIO_Port, TEST_PIN_Pin, GPIO_PIN_SET);
			systemState.controlState.controlTaskState = CONTROL_POWERLOSS;
			fanForceOff();
			setDutyCycle(0.5);
		}
	}else{
		if(systemState.controlState.controlTaskState == CONTROL_POWERLOSS_RELAYOFF){
			if ((HAL_GetTick() - closeRelayTime) > (60*60*1000)){
				systemState.controlState.controlTaskState = CONTROL_STOPANDRESET_RELAYOFF;
			}
		}
	}
	if(__HAL_TIM_GET_FLAG(&htim4,TIM_FLAG_CC4)){
		__HAL_TIM_CLEAR_FLAG(&htim4,TIM_FLAG_CC4);
		__HAL_TIM_SET_COUNTER(&htim4,0);
	}
}


void controlStopAndReset(void){
	if(systemState.controlState.controlTaskState != CONTROL_STOPANDRESET_RELAYOFF){
		systemState.controlState.controlTaskState = CONTROL_STOPANDRESET;
	}
}



static int filterState = 0;
void calculateFilters(void){
//	filterIOut = systemState.inputs.IOUT;
//	filterUCap = systemState.controlState.UCap;
//	filterIIn  = systemState.inputs.IIN;
//	IOUT_DC = IOUT_DC * DCRATIO + filterIOut * ((float)1.0-DCRATIO);
//	IIn_DC = IIn_DC * DCRATIO + filterIIn*((float)1.0-DCRATIO);
//	filterIOut = filterIOut - IOUT_DC;
//	TM_FILTER_FIR_F32_Process(currentFIR,&filterIOut,&systemState.controlState.IOutFiltered);
//	TM_FILTER_FIR_F32_Process(uCapFIR,&filterUCap,&systemState.controlState.UCapFiltered);
//	filterState = 1; //Do extra calculations in next iteration.
	filterState++;
	//Do some calculations in slower sampling loop but in next iteration, so we keep within the time limit.
	switch(filterState){
		case 0:
			break;
		case 1:
			calculateTemperature();
			break;
		case 2:
//			pidCompute(&capacitorPid);
			break;
		case 3:
		{
			float voutDiff = setPoint.voltage - voutNow;
			if (fabsf(voutDiff)>1.0f){
				voutNow += voutDiff/500;
			}else{
				voutNow = setPoint.voltage;
			}
			break;
		}
		default:
			if(filterState >9){
				filterState = 0;
			}
		break;
	}
}

void calculateTemperature(void){
auxInputs.TEMPERATURE = 16.0f; //adcToCelsius();
	if(auxInputs.TEMPERATURE> 65.0f){

		if(auxInputs.TEMPERATURE>70.0f){
			setDutyCycle(0.0f);
			systemState.controlState.controlTaskState = CONTROL_OVERTEMPERATURE;
		}
	}
}

void calculateState(void){
		uint32_t tick = __HAL_TIM_GET_COUNTER(&htim2);
		float vBus = fmaxf(systemState.inputs.VDCBUS,10.0f);
		float maxVolt = fminf(voutNow,vBus);
		systemState.controlState.U12 = maxVolt*arm_sin_f32(50.0f*6.28f/16000.0f*tick);
		systemState.controlState.dutyCycle = systemState.controlState.U12/vBus;
}

void setDutyCycle(float dutyCycle){
	//We need about dutyCyle
	bool neg = dutyCycle<0;
	int dutyCounts = abs((int)((MAX_PWM_COUNTS)*dutyCycle));

	if (dutyCounts >= MAX_PWM_COUNTS){
		dutyCounts = MAX_PWM_COUNTS-1;
	}
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

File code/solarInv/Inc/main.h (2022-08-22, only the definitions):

#define GRIDRELAY_1_Pin GPIO_PIN_14
#define GRIDRELAY_1_GPIO_Port GPIOC
#define GRIDRELAY_0_Pin GPIO_PIN_15
#define GRIDRELAY_0_GPIO_Port GPIOC
#define ADC_IN0_Pin GPIO_PIN_0
#define ADC_IN0_GPIO_Port GPIOC
#define CURSENS_Pin GPIO_PIN_1
#define CURSENS_GPIO_Port GPIOC
#define TRAFO_Pin GPIO_PIN_2
#define TRAFO_GPIO_Port GPIOC
#define TEMPHEAT_Pin GPIO_PIN_1
#define TEMPHEAT_GPIO_Port GPIOA
#define USART2_TX_Pin GPIO_PIN_2
#define USART2_TX_GPIO_Port GPIOA
#define USART2_RX_Pin GPIO_PIN_3
#define USART2_RX_GPIO_Port GPIOA
#define VDCBUS_Pin GPIO_PIN_4
#define VDCBUS_GPIO_Port GPIOA
#define RELAY_CHECK1_Pin GPIO_PIN_5
#define RELAY_CHECK1_GPIO_Port GPIOA
#define RELAY_CHECK0_Pin GPIO_PIN_6
#define RELAY_CHECK0_GPIO_Port GPIOA
#define IO_IN0_Pin GPIO_PIN_7
#define IO_IN0_GPIO_Port GPIOA
#define ADC_IN1_Pin GPIO_PIN_4
#define ADC_IN1_GPIO_Port GPIOC
#define ISOLATION_SENSE_Pin GPIO_PIN_5
#define ISOLATION_SENSE_GPIO_Port GPIOC
#define IO_IN2_Pin GPIO_PIN_0
#define IO_IN2_GPIO_Port GPIOB
#define LCD_MIC_Pin GPIO_PIN_1
#define LCD_MIC_GPIO_Port GPIOB
#define LED_RED_Pin GPIO_PIN_2
#define LED_RED_GPIO_Port GPIOB
#define LED_YELLOW_Pin GPIO_PIN_10
#define LED_YELLOW_GPIO_Port GPIOB
#define DONOTUSECOMPATIBILITY_Pin GPIO_PIN_11
#define DONOTUSECOMPATIBILITY_GPIO_Port GPIOB
#define LED_GREEN_Pin GPIO_PIN_12
#define LED_GREEN_GPIO_Port GPIOB
#define BRIDGES_SHUTDOWN_Pin GPIO_PIN_13
#define BRIDGES_SHUTDOWN_GPIO_Port GPIOB
#define BRIDGE0_LIN_Pin GPIO_PIN_14
#define BRIDGE0_LIN_GPIO_Port GPIOB
#define BRIDGE1_LIN_Pin GPIO_PIN_15
#define BRIDGE1_LIN_GPIO_Port GPIOB
#define LED_HEARTBEAT_Pin GPIO_PIN_6
#define LED_HEARTBEAT_GPIO_Port GPIOC
#define LCD_RW_Pin GPIO_PIN_7
#define LCD_RW_GPIO_Port GPIOC
#define LCD_BACKL_Pin GPIO_PIN_8
#define LCD_BACKL_GPIO_Port GPIOC
#define LCD_SWB_Pin GPIO_PIN_9
#define LCD_SWB_GPIO_Port GPIOC
#define IO_OUT1_Pin GPIO_PIN_8
#define IO_OUT1_GPIO_Port GPIOA
#define BRIDGE0_HIN_Pin GPIO_PIN_9
#define BRIDGE0_HIN_GPIO_Port GPIOA
#define BRIDGE1_HIN_Pin GPIO_PIN_10
#define BRIDGE1_HIN_GPIO_Port GPIOA
#define IO_OUT0_Pin GPIO_PIN_11
#define IO_OUT0_GPIO_Port GPIOA
#define RS485_TXENA_Pin GPIO_PIN_12
#define RS485_TXENA_GPIO_Port GPIOA
#define IO_IN1_Pin GPIO_PIN_15
#define IO_IN1_GPIO_Port GPIOA
#define LCD_D7_Pin GPIO_PIN_10
#define LCD_D7_GPIO_Port GPIOC
#define LCD_D6_Pin GPIO_PIN_11
#define LCD_D6_GPIO_Port GPIOC
#define LCD_D4_Pin GPIO_PIN_12
#define LCD_D4_GPIO_Port GPIOC
#define LCD_SWA_Pin GPIO_PIN_2
#define LCD_SWA_GPIO_Port GPIOD
#define LCD_RS_Pin GPIO_PIN_4
#define LCD_RS_GPIO_Port GPIOB
#define LCD_ENA_Pin GPIO_PIN_5
#define LCD_ENA_GPIO_Port GPIOB
#define RS485_TX_Pin GPIO_PIN_6
#define RS485_TX_GPIO_Port GPIOB
#define RS485_RX_Pin GPIO_PIN_7
#define RS485_RX_GPIO_Port GPIOB
#define LCD_D5_Pin GPIO_PIN_8
#define LCD_D5_GPIO_Port GPIOB
#define RS485_RXENA_Pin GPIO_PIN_9
#define RS485_RXENA_GPIO_Port GPIOB

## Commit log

2022-01-02 Added PCB design, datasheets and images, first real commit
    [DCBus.sch, SB2500-battery.kicad_pcb, SB2500-battery.sch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]
2022-01-02 Added some pictures of the pcbs
2022-01-16 Added daughterboards from logic board pinout and voltages. Added logicboard size sketches and a few pictures.
    [logic_pinoutandvoltages.xlsx]
2022-07-27 Moved PCB files
    [DCBus.sch, SB2500-battery.kicad_pcb, SB2500-battery.sch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]
2022-08-22 Updated some pins and voltages
    [logic_pinoutandvoltages.xlsx]
2022-08-22 Added STM32F4 control code
2022-08-22 Added some logic board parts
2022-08-22 Logic board PCB design added (converterd from Eagle) and moved powerboard schematic drawings to other folder
    [DCBus.sch, Microcontroller.sch, Psup_5v_and_3.3v.sch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]
2022-08-22 Added logicboard pcb and schematic
2022-08-30 Updated the kicad logicboard
    [SB_LOGICBOARD_V01.kicad_pcb]
2022-08-30 Added extra timer for sinusoid generation, PWM pin settings now correct, led control improved
    [controlLoop.c, solarInv.ioc, uartcomm.c]
2022-08-30 Added front and back PCB render
2022-08-30 Added code for the old original SMA PCB
2022-09-05 Doubled sinus timer speed, Enabled RS485 only reception for now, enabled float printf

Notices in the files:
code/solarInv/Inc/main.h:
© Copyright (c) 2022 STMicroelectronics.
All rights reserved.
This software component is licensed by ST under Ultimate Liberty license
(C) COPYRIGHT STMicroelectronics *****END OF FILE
